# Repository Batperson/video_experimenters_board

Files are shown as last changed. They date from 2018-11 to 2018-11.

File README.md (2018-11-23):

# Video Experimenters Board
This is a circuit intended to facilitate experimentation with the ADV7184 video decoder and ADV7341 encoder, both from Analog Devices. 
It enables a microcontroller to display colour graphics over an NTSC or PAL video feed, by providing RGB and pixel-switch signals in sync with the video. Currently I am using this board as a basis for designing a colour OSD for multicopters and radio-controlled vehicles. See more about the project here: https://wekaosd.home.blog

To interface with the VEB you will need to do several things:
1. Provide regulated 1.8V and 3.3V power supplies
2. Program the 2 ICs using the I2C protocol via the SCK and SDA connectors. Programming scripts can be found at the Analog Devices website, or you can check the source for WekaOSD and see what I have done.
3. Feed the horizontal and vertical sync signals (HS and VS), and optionally odd/even field (FLD) and interrupt (INT) signals to your microcontroller. The microcontroller needs to lock to HS and VS, in order to send graphical output in sync with the video.
4. Generate RGB video signals, and use the fast-blank (FB) line to switch between the video feed and graphics as appropriate. RGB should be in the range of 0 - 0.7V. FB can be up to 3.3V. 
5. Connect an NTSC or PAL video source to one of the inputs, and a video monitor to one of the outputs. Component video output is also possible, and component video input should also work but I have not attempted to do so.

You will most likely want to implement a digital pixel bus with one or more bits allocated to each colour channel, and use a resistor divider to convert the digital signals to analogue RGB.

The STM32F4 series of microcontrollers are suitable microcontrollers, but any reasonably fast microcontroller should be capable. Given what has been achieved with the UzeBox project even an Arduino should be able to drive the VEB.

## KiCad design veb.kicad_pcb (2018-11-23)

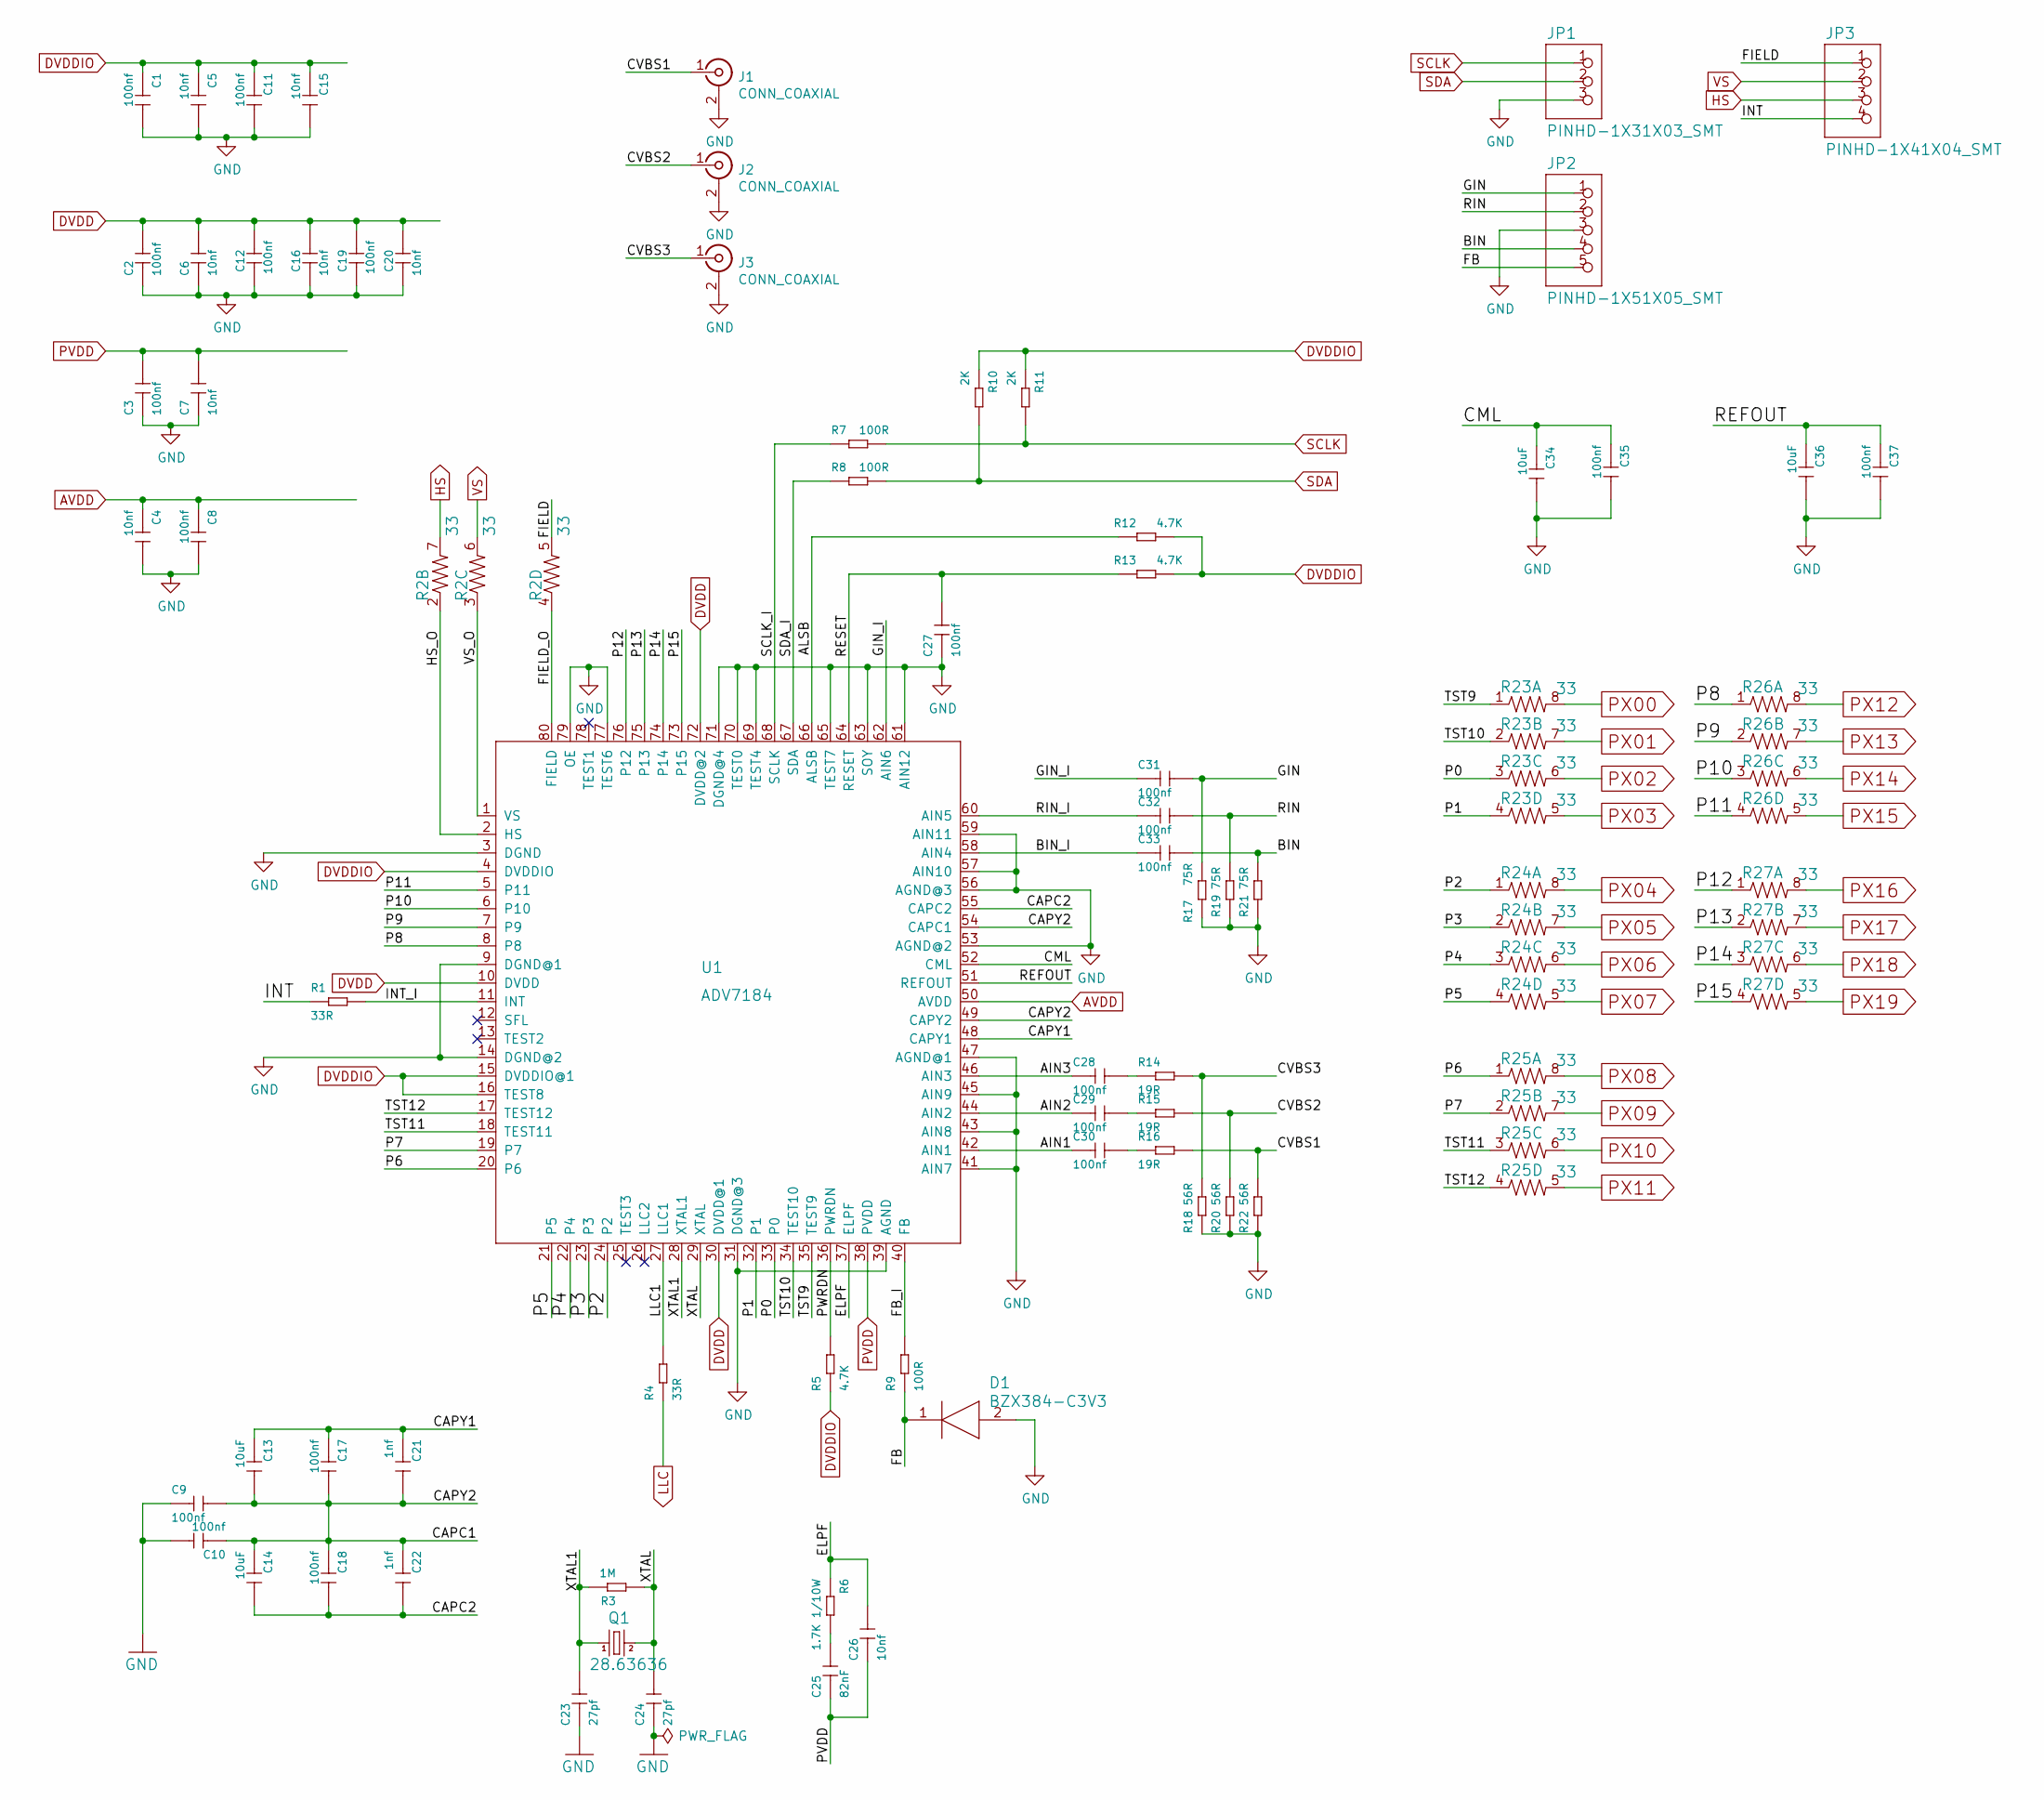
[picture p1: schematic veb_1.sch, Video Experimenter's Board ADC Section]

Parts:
C1, C2, C3, C8, C9, C10, C11, C12, C17, C18, C19, C27, C28, C29, C30, C31, C32, C33, C35, C37: 100nf; C0402
C4, C5, C6, C7, C15, C16, C20: 10nf; C0402
C13, C14, C34, C36: 10uF; C0805
C21, C22: 1nf; C0402
C23, C24: 27pf; C0402
C25: 82nF; C0805
C26: 10nf; C0805
D1: BZX384-C3V3; SOD2512X110N
J1, J2, J3: CONN_COAXIAL; RCA
JP1: PINHD-1X31X03_SMT; 1X03_SMT
JP2: PINHD-1X51X05_SMT; 1X05_SMT
JP3: PINHD-1X41X04_SMT; 1X04_SMT
Q1: 28.63636; HC49_S-SMD
R1, R4: 33R; R0603
R2, R23, R24, R25, R26, R27: 33; 0603-ARV
R3: 1M; R0603
R5, R12, R13: 4.7K; R0603
R6: 1.7K 1/10W; R0603
R7, R8, R9: 100R; R0603
R10, R11: 2K; R0603
R14, R15, R16: 19R; R0603
R17, R19, R21: 75R; R0603
R18, R20, R22: 56R; R0603
U1: ADV7184; LQFP80

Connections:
/veb_1/AIN1: C30.1, U1.42 (AIN1)
/veb_1/AIN2: C29.1, U1.44 (AIN2)
/veb_1/AIN3: C28.1, U1.46 (AIN3)
/veb_1/ALSB: R12.2, U1.66 (ALSB)
/veb_1/BIN: C33.2, JP2.4, R21.2
/veb_1/BIN_I: C33.1, U1.58 (AIN4)
/veb_1/CAPC1: C9.2, C10.1, C13.2, C14.1, C17.2, C18.1, C21.2, C22.1, U1.49 (CAPY2), U1.54 (CAPC1)
/veb_1/CAPC2: C14.2, C18.2, C22.2, U1.55 (CAPC2)
/veb_1/CAPY1: C13.1, C17.1, C21.1, U1.48 (CAPY1)
/veb_1/CML: C34.1, C35.1, U1.52 (CML)
/veb_1/CVBS1: J1.1 (In), R16.2, R22.2
/veb_1/CVBS2: J2.1 (In), R15.2, R20.2
/veb_1/CVBS3: J3.1 (In), R14.2, R18.2
/veb_1/ELPF: C26.2, R6.1, U1.37 (ELPF)
/veb_1/FB: D1.1 (K), JP2.5, R9.1
/veb_1/FB_I: R9.2, U1.40 (FB)
/veb_1/FIELD: JP3.1, R2.5 (2)
/veb_1/FIELD_O: R2.4 (1), U1.80 (FIELD)
/veb_1/GIN: C31.2, JP2.1, R17.1
/veb_1/GIN_I: C31.1, U1.62 (AIN6)
/veb_1/HS_O: R2.2 (1), U1.2 (HS)
/veb_1/INT: JP3.4, R1.1
/veb_1/INT_I: R1.2, U1.11 (INT)
/veb_1/LLC1: R4.2, U1.27 (LLC1)
/veb_1/P0: R23.3 (1), U1.33 (P0)
/veb_1/P1: R23.4 (1), U1.32 (P1)
/veb_1/P2: R24.1, U1.24 (P2)
/veb_1/P3: R24.2 (1), U1.23 (P3)
/veb_1/P4: R24.3 (1), U1.22 (P4)
/veb_1/P5: R24.4 (1), U1.21 (P5)
/veb_1/P6: R25.1, U1.20 (P6)
/veb_1/P7: R25.2 (1), U1.19 (P7)
/veb_1/P8: R26.1, U1.8
/veb_1/P9: R26.2 (1), U1.7 (P9)
/veb_1/P10: R26.3 (1), U1.6 (P10)
/veb_1/P11: R26.4 (1), U1.5 (P11)
/veb_1/P12: R27.1, U1.76 (P12)
/veb_1/P13: R27.2 (1), U1.75 (P13)
/veb_1/P14: R27.3 (1), U1.74 (P14)
/veb_1/P15: R27.4 (1), U1.73 (P15)
/veb_1/PWRDN: R5.2, U1.36 (PWRDN)
/veb_1/REFOUT: C36.1, C37.1, U1.51 (REFOUT)
/veb_1/RESET: C27.2, R13.2, U1.64 (RESET)
/veb_1/RIN: C32.2, JP2.2, R19.2
/veb_1/RIN_I: C32.1, U1.60 (AIN5)
/veb_1/SCLK_I: R7.1, U1.68 (SCLK)
/veb_1/SDA_I: R8.1, U1.67 (SDA)
/veb_1/TST9: R23.1, U1.35 (TEST9)
/veb_1/TST10: R23.2 (1), U1.34 (TEST10)
/veb_1/TST11: R25.3 (1), U1.18 (TEST11)
/veb_1/TST12: R25.4 (1), U1.17 (TEST12)
/veb_1/VS_O: R2.3 (1), U1.1 (VS)
/veb_1/XTAL: C24.2, Q1.2, R3.1, U1.29 (XTAL)
/veb_1/XTAL1: C23.2, Q1.1, R3.2, U1.28 (XTAL1)
AVDD: C4.1, C8.1, U1.50 (AVDD); also elsewhere on the board
DVDD: C2.2, C6.2, C12.1, C16.1, C19.1, C20.1, U1.10 (DVDD), U1.30 (DVDD@1), U1.72 (DVDD@2); also elsewhere on the board
DVDDIO: C1.1, C5.1, C11.1, C15.1, R5.1, R10.1, R11.1, R12.1, R13.1, U1.4 (DVDDIO), U1.15 (DVDDIO@1), U1.16 (TEST8); also elsewhere on the board
GND: C1.2, C2.1, C3.1, C4.2, C5.2, C6.1, C7.1, C8.2, C9.1, C10.2, C11.2, C12.2, C15.2, C16.2, C19.2, C20.2, C23.1, C24.1, C27.1, C34.2, C35.2, C36.2, C37.2, D1.2 (A), J1.2 (Ext), J2.2 (Ext), J3.2 (Ext), JP1.3, JP2.3, R17.2, R18.1, R19.1, R20.1, R21.1, R22.1, U1.3 (DGND), U1.9 (DGND@1), U1.14 (DGND@2), U1.31 (DGND@3), U1.39 (AGND), U1.41 (AIN7), U1.43 (AIN8), U1.45 (AIN9), U1.47 (AGND@1), U1.53 (AGND@2), U1.56 (AGND@3), U1.57 (AIN10), U1.59 (AIN11), U1.61 (AIN12), U1.63 (SOY), U1.65 (TEST7), U1.69 (TEST4), U1.70 (TEST0), U1.71 (DGND@4), U1.77 (TEST6), U1.79 (OE); also elsewhere on the board
HS: JP3.3, R2.7 (2); also elsewhere on the board
LLC: R4.1; also elsewhere on the board
unnamed: C25.2, R6.2
unnamed: C28.2, R14.1
unnamed: C29.2, R15.1
unnamed: C30.2, R16.1
PVDD: C3.2, C7.2, C25.1, C26.1, U1.38 (PVDD); also elsewhere on the board
PX00: R23.8 (2); also elsewhere on the board
PX01: R23.7 (2); also elsewhere on the board
PX02: R23.6 (2); also elsewhere on the board
PX03: R23.5 (2); also elsewhere on the board
PX04: R24.8 (2); also elsewhere on the board
PX05: R24.7 (2); also elsewhere on the board
PX06: R24.6 (2); also elsewhere on the board
PX07: R24.5 (2); also elsewhere on the board
PX08: R25.8 (2); also elsewhere on the board
PX09: R25.7 (2); also elsewhere on the board
PX10: R25.6 (2); also elsewhere on the board
PX11: R25.5 (2); also elsewhere on the board
PX12: R26.8 (2); also elsewhere on the board
PX13: R26.7 (2); also elsewhere on the board
PX14: R26.6 (2); also elsewhere on the board
PX15: R26.5 (2); also elsewhere on the board
PX16: R27.8 (2); also elsewhere on the board
PX17: R27.7 (2); also elsewhere on the board
PX18: R27.6 (2); also elsewhere on the board
PX19: R27.5 (2); also elsewhere on the board
SCLK: JP1.1, R7.2, R11.2; also elsewhere on the board
SDA: JP1.2, R8.2, R10.2; also elsewhere on the board
VS: JP3.2, R2.6 (2); also elsewhere on the board

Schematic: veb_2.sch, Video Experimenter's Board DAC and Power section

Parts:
C38, C39, C42, C45, C48, C52: 100nf; C0402
C40, C41, C46, C47, C49: 10nf; C0402
C43: 1UF 6.3V; C0402
C44, C55: 220uF; CPOL-RADIAL-100UF-25V
C50, C51, C56, C61: 33uF; EIA3528
C53, C54: 2.2nf; C0402
C57, C58: 12nf; C0402
C59, C60: 150NF; C0402
FL1, FL2, FL3, FL4: NFE61PT472C1H9L; 6816
J4, J5, J6: CONN_COAXIAL; RCA
JP4, JP5: PINHD-1X31X03_SMT; 1X03_SMT
R28: 4.7K; R0603
R29: 510R (0.1% / 1%); R0603
R30: 4.12K (0.1% / 1%); R0603
R31: 4.7k; R0603
R32, R33: 100R; R0603
R34, R37, R40: 75R; R0603
R35, R36: 33R; R0603
R38, R39: 170R; R0603
U2: ADV7341BSTZ; ST_64_2

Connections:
+1V8: C55.1, FL3.1, FL4.1, JP4.3
+3V3: C44.1, FL1.1, FL2.1, JP4.1
/veb_2/ALSB: R31.1, U2.19
/veb_2/COMP1: C53.2, U2.45
/veb_2/COMP2: C54.1, U2.35
/veb_2/DAC1: J4.1 (In), R34.2, U2.44
/veb_2/DAC2: J5.1 (In), R37.2, U2.43
/veb_2/DAC3: J6.1 (In), R40.2, U2.42
/veb_2/EXT_LF1: C57.1, R38.1, U2.33
/veb_2/EXT_LF2: C58.1, R39.1, U2.31
/veb_2/RSET1: R29.1, U2.47
/veb_2/RSET2: R30.1, U2.36
/veb_2/SCLK_I: R33.1, U2.21
/veb_2/SDA_I: R32.1, U2.20
/veb_2/TT_IN_I: R36.1, U2.48
/veb_2/TT_RQ_O: R35.1, U2.23
/veb_2/VREF: C52.2, U2.46
AVDD: C43.2, C45.2, C47.2, C50.A, C52.1, C53.1, C54.2, FL1.3, U2.41; also elsewhere on the board
DVDD: C42.1, C46.1, C48.1, C49.1, C61.A, FL4.3, U2.10, U2.56; also elsewhere on the board
DVDDIO: C39.1, C41.1, C51.A, FL2.3, R28.1, R31.2, U2.1; also elsewhere on the board
GND: C38.2, C39.2, C40.2, C41.2, C42.2, C43.1, C44.2, C45.1, C46.2, C47.1, C48.2, C49.2, C50.C, C51.C, C55.2, C56.C, C61.C, FL1.2, FL2.2, FL3.2, FL4.2, J4.2 (Ext), J5.2 (Ext), J6.2 (Ext), JP4.2, JP5.2, R29.2, R30.2, R34.1, R37.1, R40.1, U2.11, U2.32, U2.37, U2.38, U2.39, U2.40, U2.51, U2.52, U2.53, U2.54, U2.55, U2.57, U2.58, U2.59, U2.60, U2.61, U2.62, U2.63, U2.64; also elsewhere on the board
HS: U2.50; also elsewhere on the board
LLC: U2.30; also elsewhere on the board
unnamed: C59.1, R38.2
unnamed: C60.1, R39.2
unnamed: JP5.1, R35.2
unnamed: JP5.3, R36.2
unnamed: R28.2, U2.22, U2.24
PVDD: C38.1, C40.1, C56.A, C57.2, C58.2, C59.2, C60.2, FL3.3, U2.34; also elsewhere on the board
PX00: U2.14; also elsewhere on the board
PX01: U2.15; also elsewhere on the board
PX02: U2.16; also elsewhere on the board
PX03: U2.17; also elsewhere on the board
PX04: U2.18; also elsewhere on the board
PX05: U2.25; also elsewhere on the board
PX06: U2.26; also elsewhere on the board
PX07: U2.27; also elsewhere on the board
PX08: U2.28; also elsewhere on the board
PX09: U2.29; also elsewhere on the board
PX10: U2.2; also elsewhere on the board
PX11: U2.3; also elsewhere on the board
PX12: U2.4; also elsewhere on the board
PX13: U2.5; also elsewhere on the board
PX14: U2.6; also elsewhere on the board
PX15: U2.7; also elsewhere on the board
PX16: U2.8; also elsewhere on the board
PX17: U2.9; also elsewhere on the board
PX18: U2.12; also elsewhere on the board
PX19: U2.13; also elsewhere on the board
SCLK: R33.2; also elsewhere on the board
SDA: R32.2; also elsewhere on the board
VS: U2.49; also elsewhere on the board

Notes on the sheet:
As close as possible and on same side as ADV7341

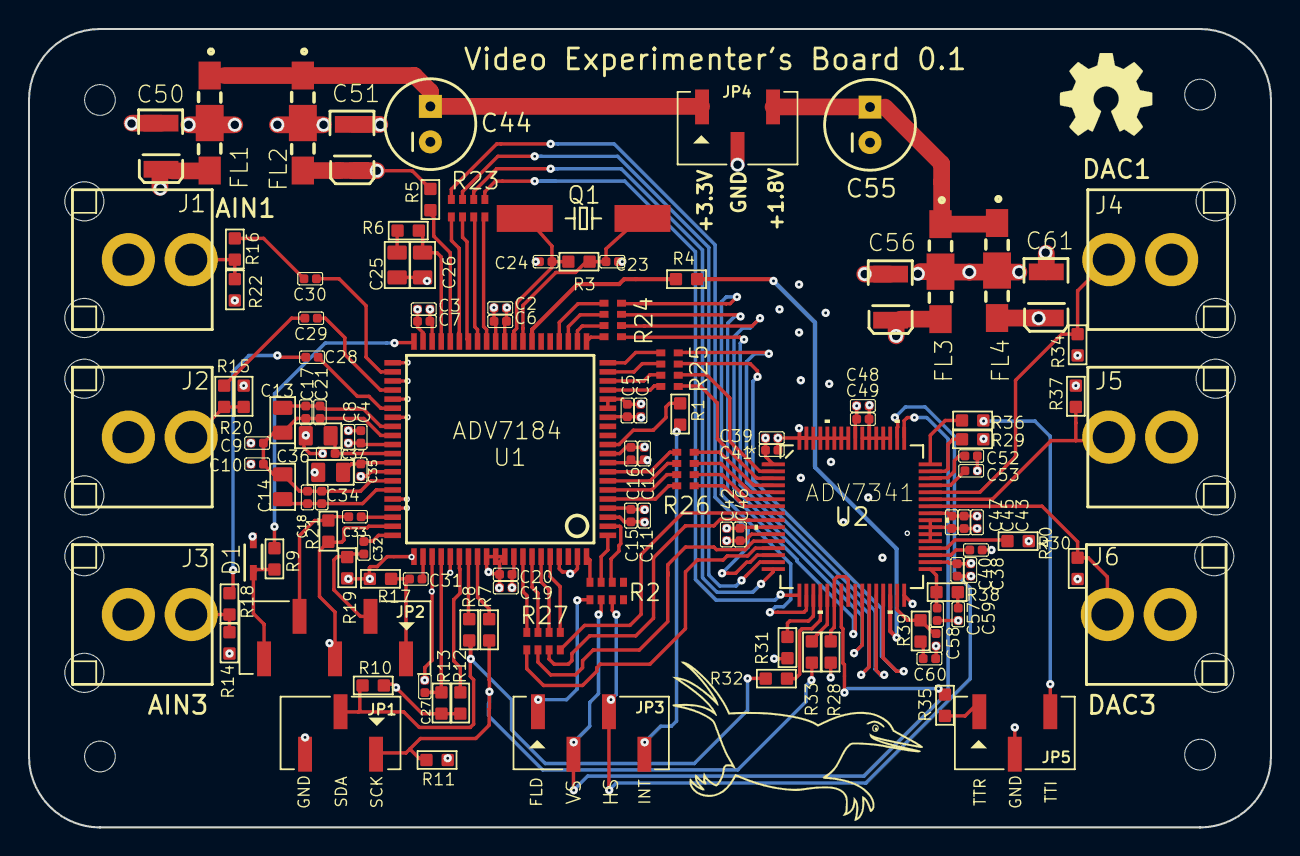
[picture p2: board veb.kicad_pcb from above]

Board: 4 copper layers, 88.9 x 57.2 mm, 120 parts (0 on the bottom side), 110 nets.
